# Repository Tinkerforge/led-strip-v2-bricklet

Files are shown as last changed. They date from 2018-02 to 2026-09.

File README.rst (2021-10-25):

LED Strip Bricklet 2.0
======================

This repository contains the firmware source code and the hardware design
files. The documentation generator configs can be found at
https://github.com/Tinkerforge/generators

Repository Content
------------------

software/:
 * examples/: Examples for all supported languages
 * build/: Compiled files
 * src/: Source code of firmware
 * Makefile: Makefile to build project

hardware/:
 * Contains KiCad project files and additionally schematics as PDF

datasheets/:
 * Contains datasheets for sensors and complex ICs that are used

Hardware
--------

The hardware is designed with the open source EDA Suite KiCad
(http://www.kicad.org). Before you are able to open the files,
you have to install the Tinkerforge kicad-libraries
(https://github.com/Tinkerforge/kicad-libraries). You can either clone
them directly in hardware/ or clone them in a separate folder and
symlink them into hardware/
(ln -s kicad_path/kicad-libraries project_path/hardware). After that you
can open the .pro file in hardware/ with KiCad and from there view and
modify the schematics and the PCB layout.

Software
--------

If you want to do your own Brick/Bricklet firmware development we highly
recommend that you use our build environment setup script and read the
tutorial (https://www.tinkerforge.com/en/doc/Tutorials/Tutorial_Build_Environment/Tutorial.html).

To compile the C code we recommend you to install the newest GNU Arm Embedded
Toolchain (https://launchpad.net/gcc-arm-embedded/+download).
You also need to install bricklib2 (https://github.com/Tinkerforge/bricklib2).

You can either clone it directly in software/src/ or clone it in a
separate folder and symlink it into software/src/
(ln -s bricklib_path/bricklib2 project_path/software/src/). Finally make sure to
have CMake installed (http://www.cmake.org/cmake/resources/software.html).

After that you can build the firmware by invoking make in software/.
The firmware (.zbin) can then be found in software/build/ and uploaded
with brickv (click button "Flashing" on start screen).

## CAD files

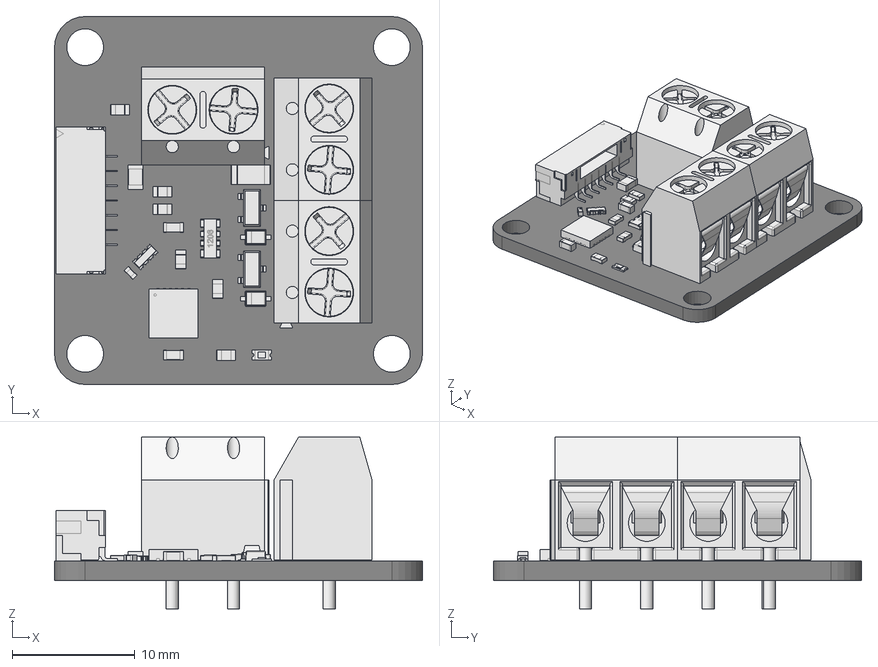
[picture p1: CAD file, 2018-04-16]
hardware/led-strip-v2.FCStd
30.0 x 30.0 x 14.0 mm
Pcb
SOD323F_
SOD323F_001
SOT23_
SOT23_001
2er_Buchse_
2er_Buchse_001
2er_Buchse_002
F_1206_
C_0402_
C_0805_
C_0603_
C_0603_001
R_0603_
BrickletConn_7pin_
R_0603_001
R_0603_002
R_4x0603_
QFN-24_4x4mm_Pitch0.5mm_
D_0603_blue_
R_0603_003
R_0603_004
R_0603_005

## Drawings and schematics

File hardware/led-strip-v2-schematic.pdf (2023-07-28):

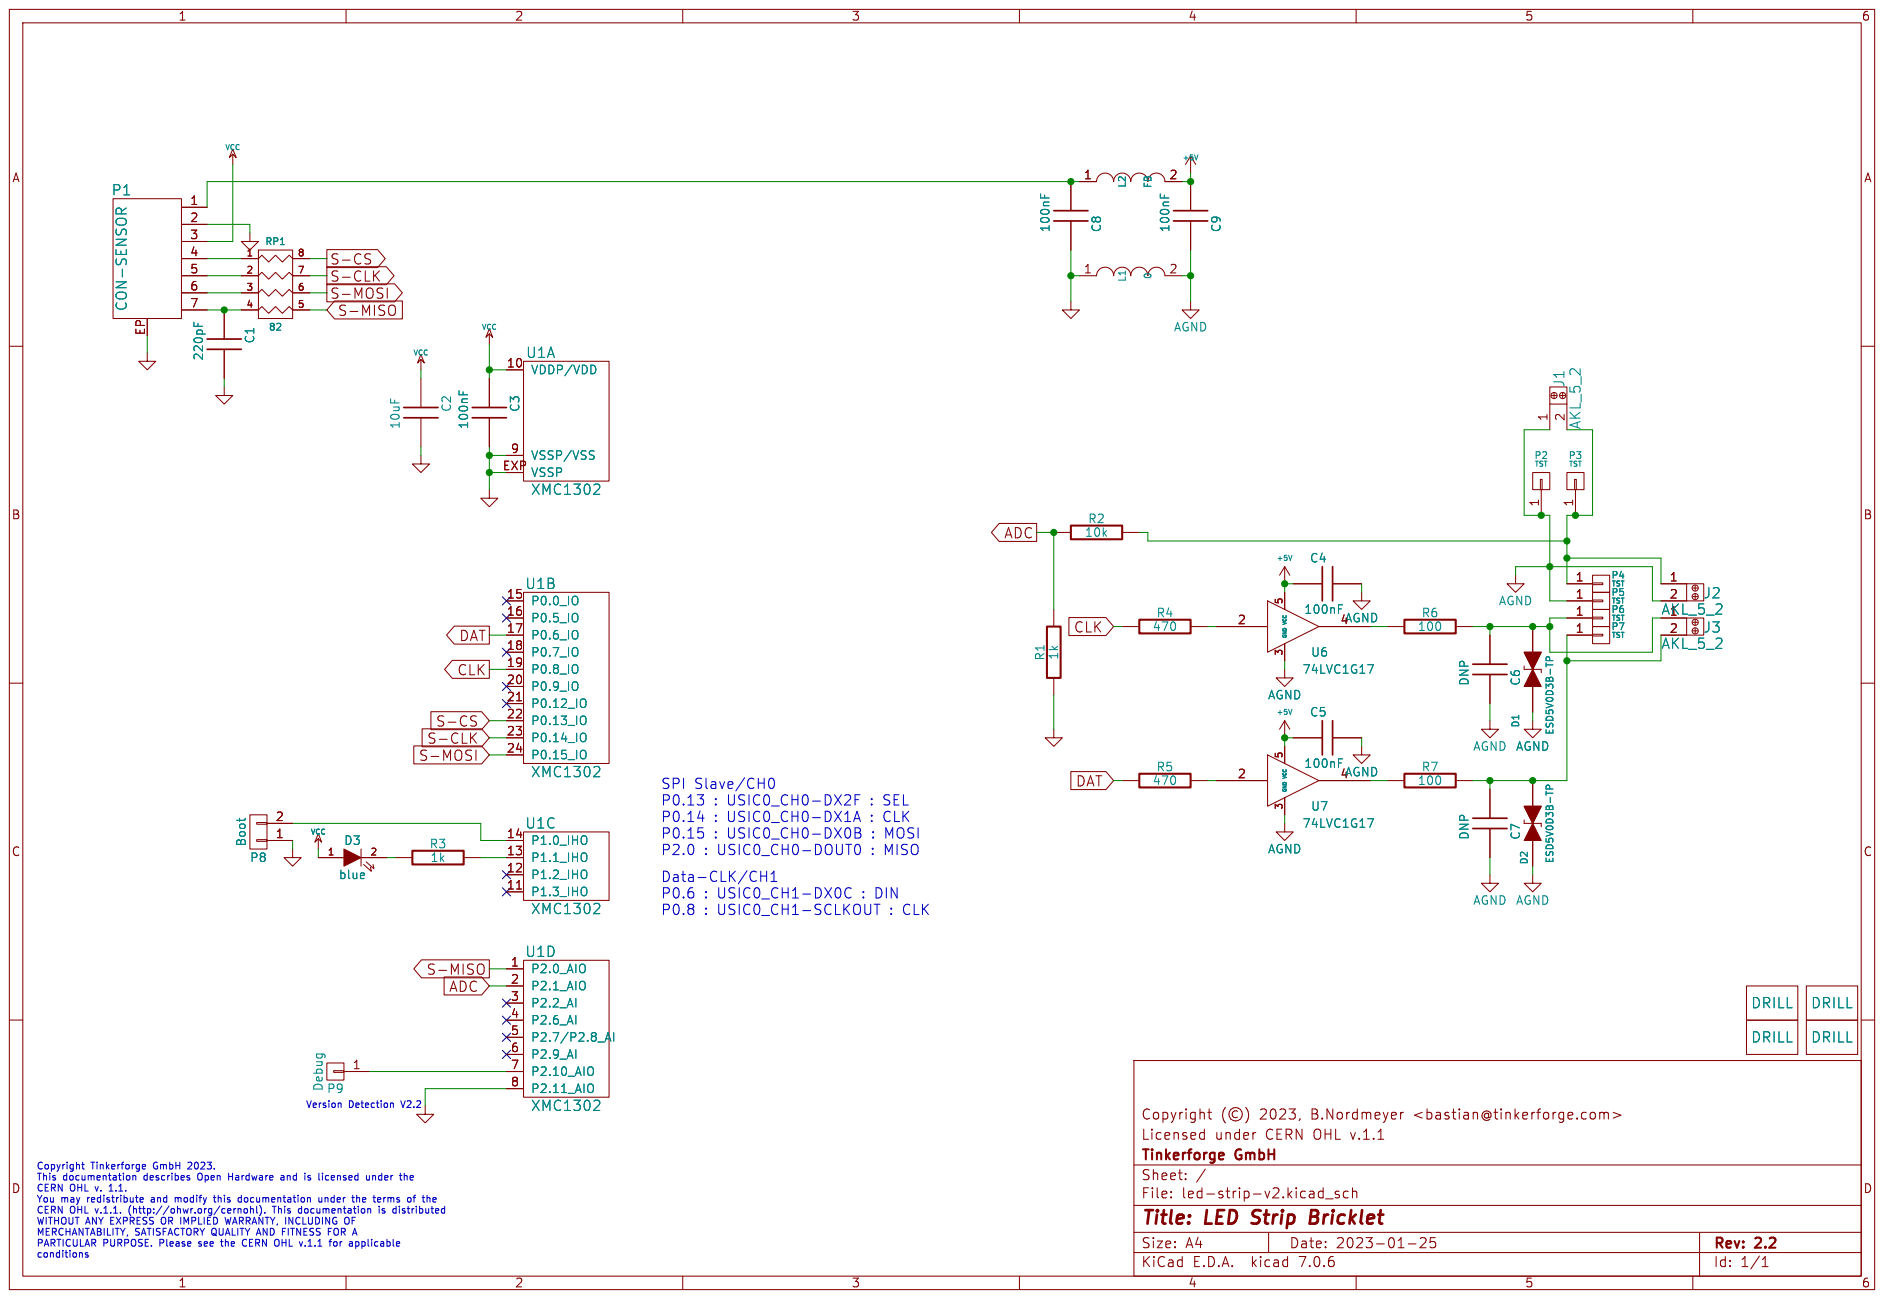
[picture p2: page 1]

Licensed | | under CERN OHL v.1.1 Copyright þÿ(©)2023, | B.Nordmeyer | <bastian@tinkerforge.com>

Id: 1/1 Title: LED Strip Bricklet File: led-strip-v2.kicad_sch Sheet: / Tinkerforge GmbH

PARTICULAR PURPOSE. Please see the CERN OHL v.1.1 for applicable

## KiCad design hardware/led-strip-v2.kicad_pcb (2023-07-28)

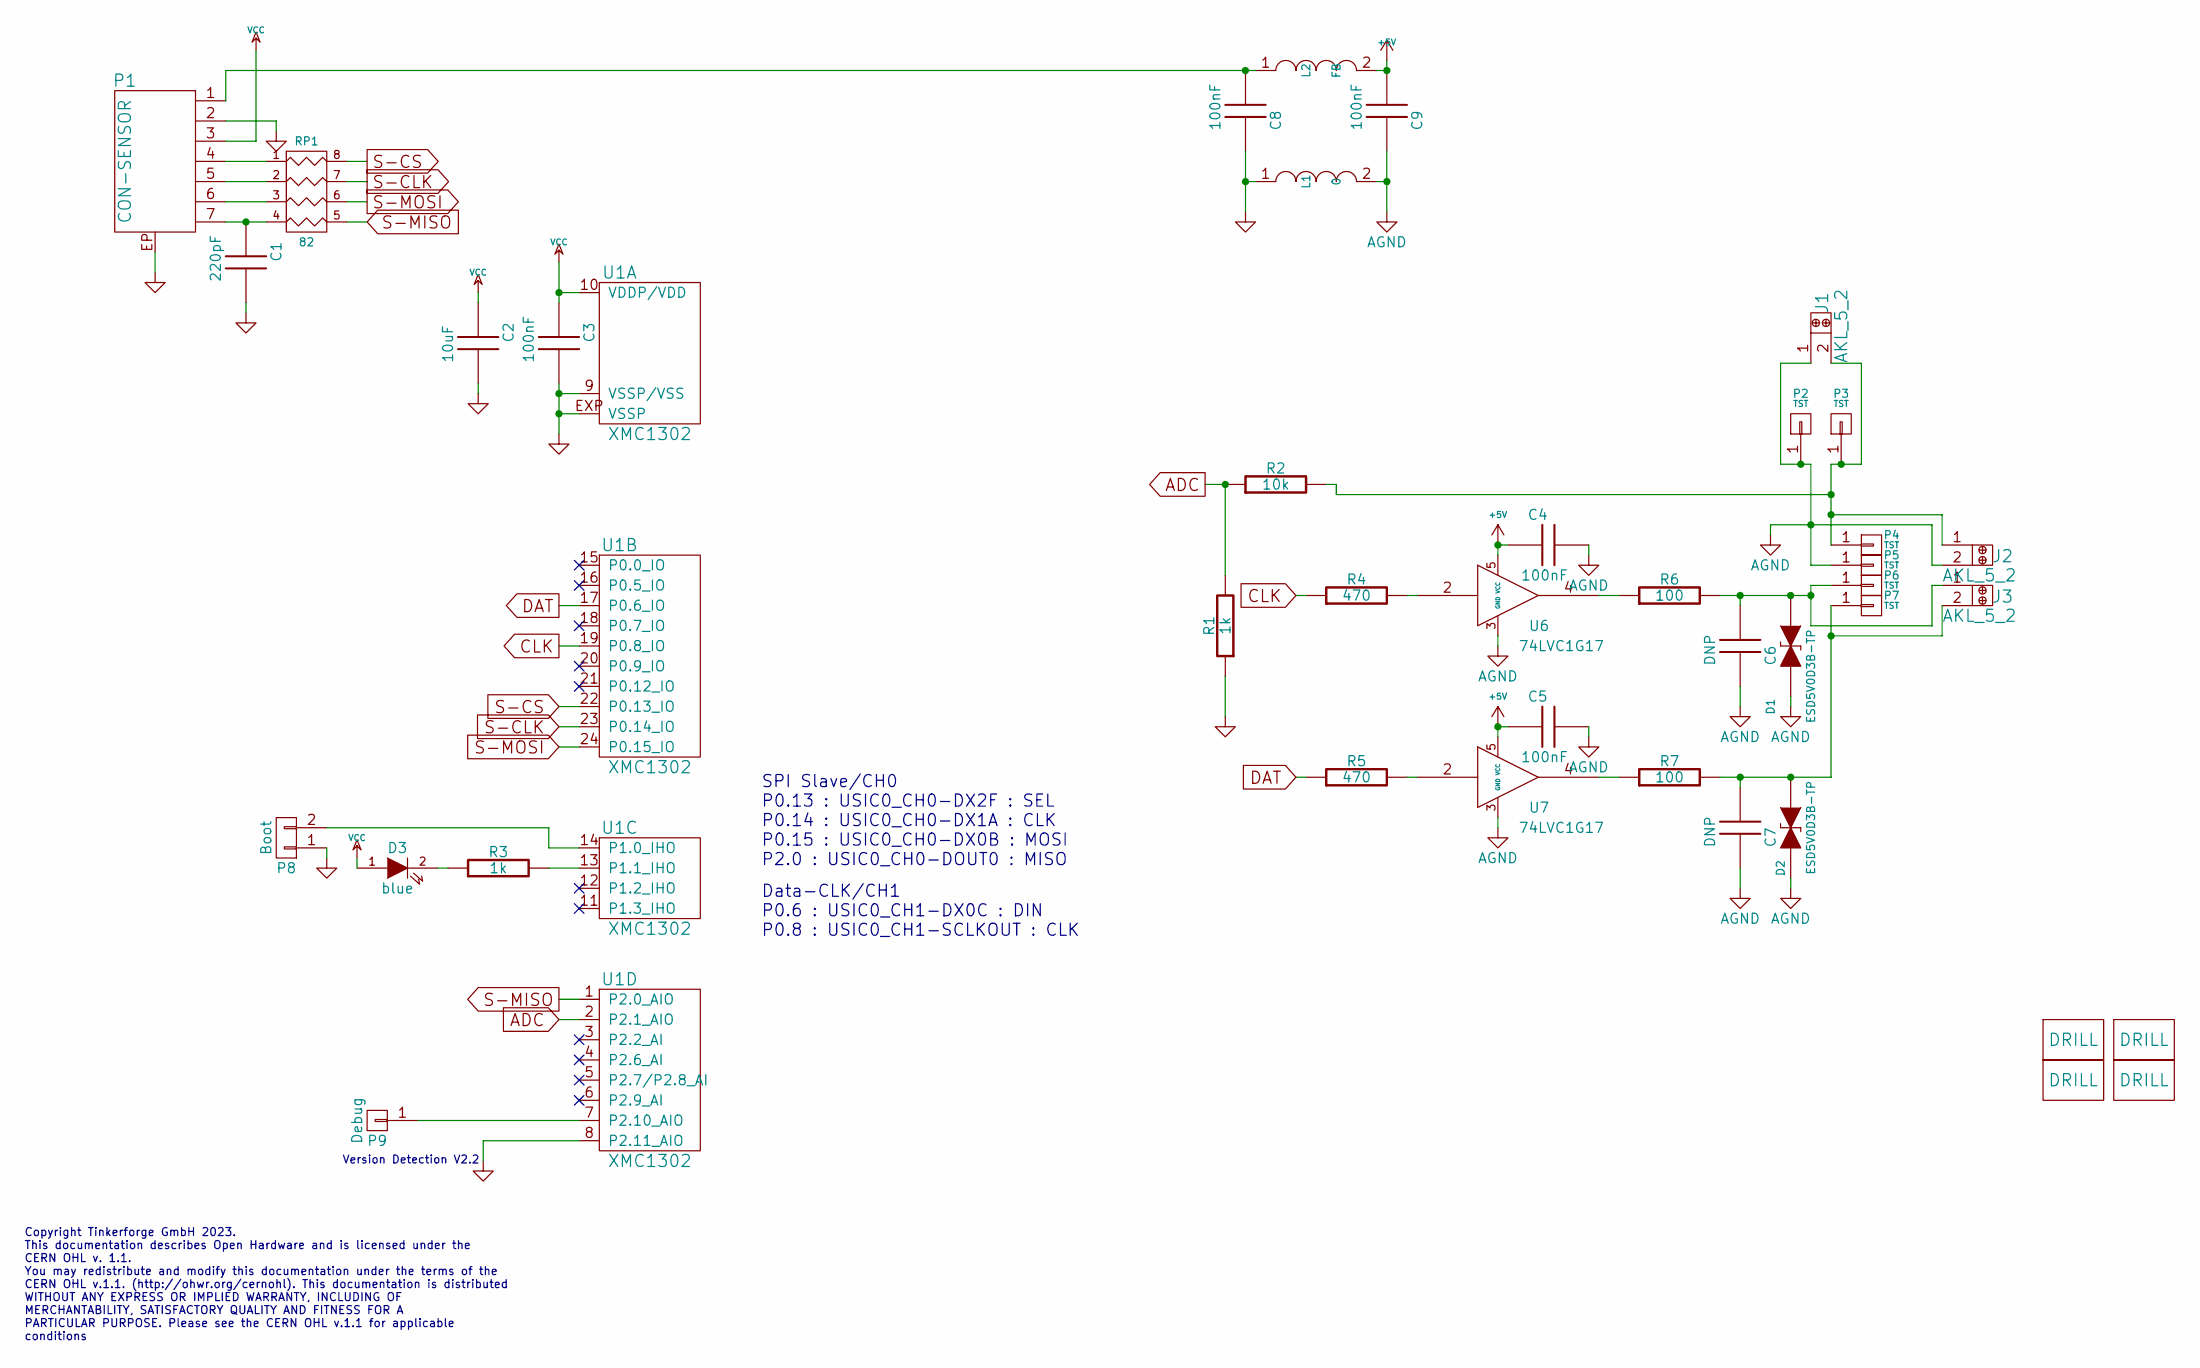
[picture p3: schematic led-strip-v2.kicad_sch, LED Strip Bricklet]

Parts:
C1: 220pF; C0402F
C2: 10uF; C0805E
C3, C4, C5, C8, C9: 100nF; C0603F
C6, C7: DNP; C0603F
D1, D2: ESD5V0D3B-TP; SOD-323
D3: blue; D0603F
J1, J2, J3: AKL_5_2
L1: 0; R0603F
L2: FB; R0603F
P1: CON-SENSOR; CON-SENSOR2
P2, P3, P4, P5, P6, P7: TST; SOLDER_PAD2
P8: Boot; SolderJumper
P9: Debug; DEBUG_PAD
R1, R3: 1k; R0603F
R2: 10k; R0603F
R4, R5: 470; R0603F
R6, R7: 100; R0603F
RP1: 82; 4X0402
U1: XMC1302; QFN24-4x4mm-0.5mm
U2, U3, U4, U5: DRILL; DRILL_NP
U6, U7: 74LVC1G17; SOT23-5

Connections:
+5V: C4.1, C5.1, C9.1, L2.2, U6.5 (VCC), U7.5 (VCC)
ADC: R1.2, R2.1, U1.2 (P2.1_AIO)
AGND: C4.2, C5.2, C6.2, C7.2, C9.2, D1.2 (K), D2.2 (K), J1.1, J2.2, L1.2, P2.1, P5.1, U6.3 (GND), U7.3 (GND)
CLK: R4.1, U1.19 (P0.8_IO)
DAT: R5.1, U1.17 (P0.6_IO)
GND: C1.2, C2.2, C3.2, C8.2, L1.1, P1.2, P1.EP, P8.1, R1.1, U1.8 (P2.11_AIO), U1.9 (VSSP/VSS), U1.EXP (VSSP)
unnamed: C1.1, P1.7, RP1.4
unnamed: C6.1, D1.1 (A), J3.1, P6.1, R6.2
unnamed: C7.1, D2.1 (A), J3.2, P7.1, R7.2
unnamed: C8.1, L2.1, P1.1
unnamed: D3.2 (K), R3.1
unnamed: J1.2, J2.1, P3.1, P4.1, R2.2
unnamed: P1.4, RP1.1
unnamed: P1.5, RP1.2
unnamed: P1.6, RP1.3
unnamed: P8.2, U1.14 (P1.0_IHO)
unnamed: P9.1, U1.7 (P2.10_AIO)
unnamed: R3.2, U1.13 (P1.1_IHO)
unnamed: R4.2, U6.2
unnamed: R5.2, U7.2
unnamed: R6.1, U6.4
unnamed: R7.1, U7.4
S-CLK: RP1.7 (R2), U1.23 (P0.14_IO)
S-CS: RP1.8 (R1), U1.22 (P0.13_IO)
S-MISO: RP1.5 (R4), U1.1 (P2.0_AIO)
S-MOSI: RP1.6 (R3), U1.24 (P0.15_IO)
VCC: C2.1, C3.1, D3.1 (A), P1.3, U1.10 (VDDP/VDD)

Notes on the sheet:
Copyright Tinkerforge GmbH 2023. This documentation describes Open Hardware and is licensed under the CERN OHL v. 1.1. You may redistribute and modify this documentation under the terms of the CERN OHL v.1.1. (http://ohwr.org/cernohl). This documentation is distributed WITHOUT ANY EXPRESS OR IMPLIE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
Version Detection V2.2
SPI Slave/CH0 P0.13 : USIC0_CH0-DX2F : SEL P0.14 : USIC0_CH0-DX1A : CLK P0.15 : USIC0_CH0-DX0B : MOSI P2.0 : USIC0_CH0-DOUT0 : MISO
Data-CLK/CH1 P0.6 : USIC0_CH1-DX0C : DIN P0.8 : USIC0_CH1-SCLKOUT : CLK

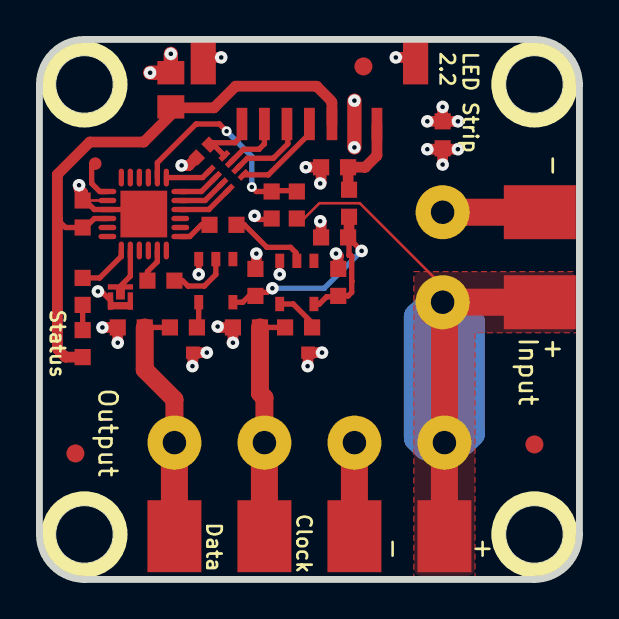
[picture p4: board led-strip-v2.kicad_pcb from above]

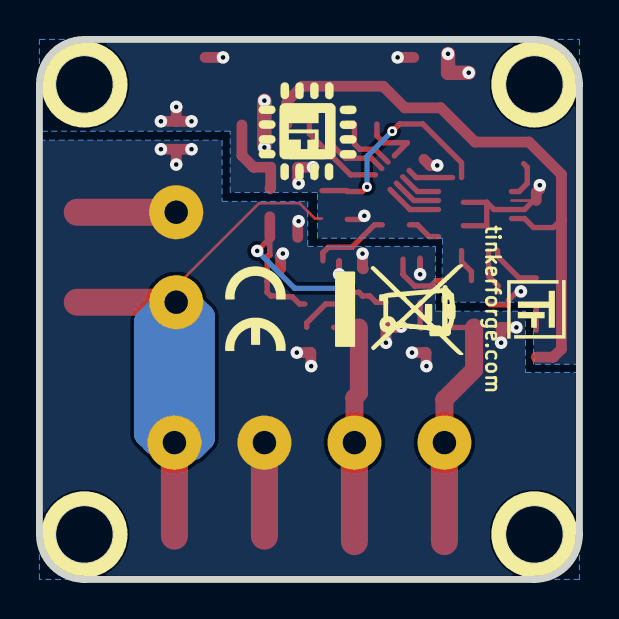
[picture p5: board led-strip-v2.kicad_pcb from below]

Board: 2 copper layers, 30.0 x 30.0 mm, 46 parts (2 on the bottom side), 27 nets.

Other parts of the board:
Fiducial_Mark: VAL**; Fiducial_Mark
Fiducial_Mark#2, Fiducial_Mark#3: VAL**; Fiducial_Mark
VAL: CE_5mm
VAL#2: WEEE_7mm

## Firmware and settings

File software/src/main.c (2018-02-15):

/* led-strip-v2-bricklet
 * Copyright (C) 2018 Olaf Lüke <olaf@tinkerforge.com>
 *
 * main.c: Initialization for LED Strip V2 Bricklet
 *
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
 * You should have received a copy of the GNU Lesser General Public
 * License along with this library; if not, write to the
 * Free Software Foundation, Inc., 59 Temple Place - Suite 330,
 * Boston, MA 02111-1307, USA.
 */

#include <stdio.h>
#include <stdbool.h>

#include "configs/config.h"

#include "bricklib2/bootloader/bootloader.h"
#include "bricklib2/hal/system_timer/system_timer.h"
#include "bricklib2/logging/logging.h"
#include "communication.h"
#include "led.h"

int main(void) {
	logging_init();
	logd("Start LED Strip V2 Bricklet\n\r");

	communication_init();
	led_init();

	while(true) {
		bootloader_tick();
		communication_tick();
		led_tick();
	}
}

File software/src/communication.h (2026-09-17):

/* led-strip-v2-bricklet
 * Copyright (C) 2018 Olaf Lüke <olaf@tinkerforge.com>
 *
 * communication.h: TFP protocol message handling
 *
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
 * You should have received a copy of the GNU Lesser General Public
 * License along with this library; if not, write to the
 * Free Software Foundation, Inc., 59 Temple Place - Suite 330,
 * Boston, MA 02111-1307, USA.
 */

#ifndef COMMUNICATION_H
#define COMMUNICATION_H

#include <stdint.h>
#include <stdbool.h>

#include "bricklib2/protocols/tfp/tfp.h"
#include "bricklib2/bootloader/bootloader.h"

// Default functions
BootloaderHandleMessageResponse handle_message(const void *data, void *response);
void communication_tick(void);
void communication_init(void);

// Constants

#define LED_STRIP_V2_CHIP_TYPE_WS2801 2801
#define LED_STRIP_V2_CHIP_TYPE_WS2811 2811
#define LED_STRIP_V2_CHIP_TYPE_WS2812 2812
#define LED_STRIP_V2_CHIP_TYPE_LPD8806 8806
#define LED_STRIP_V2_CHIP_TYPE_APA102 102

#define LED_STRIP_V2_CHANNEL_MAPPING_RGB 6
#define LED_STRIP_V2_CHANNEL_MAPPING_RBG 9
#define LED_STRIP_V2_CHANNEL_MAPPING_BRG 33
#define LED_STRIP_V2_CHANNEL_MAPPING_BGR 36
#define LED_STRIP_V2_CHANNEL_MAPPING_GRB 18
#define LED_STRIP_V2_CHANNEL_MAPPING_GBR 24
#define LED_STRIP_V2_CHANNEL_MAPPING_RGBW 27
#define LED_STRIP_V2_CHANNEL_MAPPING_RGWB 30
#define LED_STRIP_V2_CHANNEL_MAPPING_RBGW 39
#define LED_STRIP_V2_CHANNEL_MAPPING_RBWG 45
#define LED_STRIP_V2_CHANNEL_MAPPING_RWGB 54
#define LED_STRIP_V2_CHANNEL_MAPPING_RWBG 57
#define LED_STRIP_V2_CHANNEL_MAPPING_GRWB 78
#define LED_STRIP_V2_CHANNEL_MAPPING_GRBW 75
#define LED_STRIP_V2_CHANNEL_MAPPING_GBWR 108
#define LED_STRIP_V2_CHANNEL_MAPPING_GBRW 99
#define LED_STRIP_V2_CHANNEL_MAPPING_GWBR 120
#define LED_STRIP_V2_CHANNEL_MAPPING_GWRB 114
#define LED_STRIP_V2_CHANNEL_MAPPING_BRGW 135
#define LED_STRIP_V2_CHANNEL_MAPPING_BRWG 141
#define LED_STRIP_V2_CHANNEL_MAPPING_BGRW 147
#define LED_STRIP_V2_CHANNEL_MAPPING_BGWR 156
#define LED_STRIP_V2_CHANNEL_MAPPING_BWRG 177
#define LED_STRIP_V2_CHANNEL_MAPPING_BWGR 180
#define LED_STRIP_V2_CHANNEL_MAPPING_WRBG 201
#define LED_STRIP_V2_CHANNEL_MAPPING_WRGB 198
#define LED_STRIP_V2_CHANNEL_MAPPING_WGBR 216
#define LED_STRIP_V2_CHANNEL_MAPPING_WGRB 210
#define LED_STRIP_V2_CHANNEL_MAPPING_WBGR 228
#define LED_STRIP_V2_CHANNEL_MAPPING_WBRG 225

#define LED_STRIP_V2_BOOTLOADER_MODE_BOOTLOADER 0
#define LED_STRIP_V2_BOOTLOADER_MODE_FIRMWARE 1
#define LED_STRIP_V2_BOOTLOADER_MODE_BOOTLOADER_WAIT_FOR_REBOOT 2
#define LED_STRIP_V2_BOOTLOADER_MODE_FIRMWARE_WAIT_FOR_REBOOT 3
#define LED_STRIP_V2_BOOTLOADER_MODE_FIRMWARE_WAIT_FOR_ERASE_AND_REBOOT 4

#define LED_STRIP_V2_BOOTLOADER_STATUS_OK 0
#define LED_STRIP_V2_BOOTLOADER_STATUS_INVALID_MODE 1
#define LED_STRIP_V2_BOOTLOADER_STATUS_NO_CHANGE 2
#define LED_STRIP_V2_BOOTLOADER_STATUS_ENTRY_FUNCTION_NOT_PRESENT 3
#define LED_STRIP_V2_BOOTLOADER_STATUS_DEVICE_IDENTIFIER_INCORRECT 4
#define LED_STRIP_V2_BOOTLOADER_STATUS_CRC_MISMATCH 5

#define LED_STRIP_V2_STATUS_LED_CONFIG_OFF 0
#define LED_STRIP_V2_STATUS_LED_CONFIG_ON 1
#define LED_STRIP_V2_STATUS_LED_CONFIG_SHOW_HEARTBEAT 2
#define LED_STRIP_V2_STATUS_LED_CONFIG_SHOW_STATUS 3

// Function and callback IDs and structs
#define FID_SET_LED_VALUES_LOW_LEVEL 1
#define FID_GET_LED_VALUES_LOW_LEVEL 2
#define FID_SET_FRAME_DURATION 3
#define FID_GET_FRAME_DURATION 4
#define FID_GET_SUPPLY_VOLTAGE 5
#define FID_SET_CLOCK_FREQUENCY 7
#define FID_GET_CLOCK_FREQUENCY 8
#define FID_SET_CHIP_TYPE 9
#define FID_GET_CHIP_TYPE 10
#define FID_SET_CHANNEL_MAPPING 11
#define FID_GET_CHANNEL_MAPPING 12
#define FID_SET_FRAME_STARTED_CALLBACK_CONFIGURATION 13
#define FID_GET_FRAME_STARTED_CALLBACK_CONFIGURATION 14
#define FID_START_FRAME 15
#define FID_TRUNCATE_FRAME 16
#define FID_SET_AUTO_TRUNCATE 17
#define FID_GET_AUTO_TRUNCATE 18

#define FID_CALLBACK_FRAME_STARTED 6

typedef struct {
	TFPMessageHeader header;
	uint16_t index;
	uint16_t value_length;
	uint16_t value_chunk_offset;
	uint8_t value_chunk_data[58];
} __attribute__((__packed__)) SetLEDValuesLowLevel;

typedef struct {
	TFPMessageHeader header;
	uint16_t index;
	uint16_t length;
} __attribute__((__packed__)) GetLEDValuesLowLevel;

typedef struct {
	TFPMessageHeader header;
	uint16_t value_length;
	uint16_t value_chunk_offset;
	uint8_t value_chunk_data[60];
} __attribute__((__packed__)) GetLEDValuesLowLevel_Response;

typedef struct {
	TFPMessageHeader header;
	uint16_t duration;
} __attribute__((__packed__)) SetFrameDuration;

typedef struct {
	TFPMessageHeader header;
} __attribute__((__packed__)) GetFrameDuration;

typedef struct {
	TFPMessageHeader header;
	uint16_t duration;
} __attribute__((__packed__)) GetFrameDuration_Response;

typedef struct {
	TFPMessageHeader header;
} __attribute__((__packed__)) GetSupplyVoltage;

typedef struct {
	TFPMessageHeader header;
	uint16_t voltage;
} __attribute__((__packed__)) GetSupplyVoltage_Response;

typedef struct {
	TFPMessageHeader header;
	uint16_t length;
} __attribute__((__packed__)) FrameStarted_Callback;

typedef struct {
	TFPMessageHeader header;
	uint32_t frequency;
} __attribute__((__packed__)) SetClockFrequency;

typedef struct {
	TFPMessageHeader header;
} __attribute__((__packed__)) GetClockFrequency;

typedef struct {
	TFPMessageHeader header;
	uint32_t frequency;
} __attribute__((__packed__)) GetClockFrequency_Response;

typedef struct {
	TFPMessageHeader header;
	uint16_t chip;
} __attribute__((__packed__)) SetChipType;

typedef struct {
	TFPMessageHeader header;
} __attribute__((__packed__)) GetChipType;

typedef struct {
	TFPMessageHeader header;
	uint16_t chip;
} __attribute__((__packed__)) GetChipType_Response;

typedef struct {
	TFPMessageHeader header;
	uint8_t mapping;
} __attribute__((__packed__)) SetChannelMapping;

typedef struct {
	TFPMessageHeader header;
} __attribute__((__packed__)) GetChannelMapping;

typedef struct {
	TFPMessageHeader header;
	uint8_t mapping;
} __attribute__((__packed__)) GetChannelMapping_Response;

typedef struct {
	TFPMessageHeader header;
	bool enable;
} __attribute__((__packed__)) SetFrameStartedCallbackConfiguration;

typedef struct {
	TFPMessageHeader header;
} __attribute__((__packed__)) GetFrameStartedCallbackConfiguration;

typedef struct {
	TFPMessageHeader header;
	bool enable;
} __attribute__((__packed__)) GetFrameStartedCallbackConfiguration_Response;

typedef struct {
	TFPMessageHeader header;
} __attribute__((__packed__)) StartFrame;

typedef struct {
	TFPMessageHeader header;
	uint16_t length;
} __attribute__((__packed__)) TruncateFrame;

typedef struct {
	TFPMessageHeader header;
	uint16_t length;
} __attribute__((__packed__)) SetAutoTruncate;

typedef struct {
	TFPMessageHeader header;
} __attribute__((__packed__)) GetAutoTruncate;

typedef struct {
	TFPMessageHeader header;
	uint16_t length;
} __attribute__((__packed__)) GetAutoTruncate_Response;
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

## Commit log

2018-01-12 add new hardware prototype
    [led_strip.kicad_pcb, led_strip.sch]
2018-01-15 change default via size
    [led_strip.kicad_pcb]
2018-02-15 specify processor
    [led_strip.kicad_pcb, led_strip.sch]
2018-02-15 Add firmware
    [cmake_config_custom.txt]
2018-02-20 Cleanup KiCad libraries config
    Ensure LibDir=kicad-libraries and LibName1=tinkerforge.
    Remove special library.
2018-03-15 fix description text
    [led_strip.kicad_pcb]
2018-03-26 Make sure that LED type is updated during initialization
2018-04-16 Add 3d model (*.FCStd & *.step)
    [led_strip.FCStd]
2018-05-04 Rename files
    [led-strip-v2.FCStd, led-strip-v2.kicad_pcb, led-strip-v2.sch]
2018-05-04 Add schematic PDF
2018-05-30 remove solder paste layer of solder pads
    [led-strip-v2.kicad_pcb]
2018-06-11 Fix bit mixup in lookup table for WS281x LEDs
    [led.c]
2018-06-13 Fix schematic filename
2018-06-18 Change capacitor footprint(s) to C0402F
    [led-strip-v2.kicad_pcb, led-strip-v2.sch]
2018-11-12 Fill in incomplete LED Strip V2 Python examples
2019-05-29 Dont disable post calibration
2019-11-20 Rewrite get_led_values. Fix streaming.
    [led.c]
2020-06-10 version 2.1, improve ground connection
    [led-strip-v2.kicad_pcb, led-strip-v2.sch]
2020-08-04 specify fuse
    [led-strip-v2.kicad_pcb, led-strip-v2.sch]
2020-09-02 uc: Add example driver note.
2021-10-25 Update KiCad link
    https://www.kicad.org/blog/2021/10/Avoid-links-to-former-kicad-domain/
2022-08-23 add 2.2 data
    [led-strip-v2.kicad_pcb, led-strip-v2.sch]
2022-09-21 add version detection pin to pcb
    [led-strip-v2.kicad_pcb]
2023-01-23 New standart layout. Switched to Kicad 6
    [led-strip-v2.kicad_pcb, led-strip-v2.kicad_sch, led-strip-v2.sch]
2023-01-25 Data Cleanup
    [led-strip-v2.kicad_pcb, led-strip-v2.kicad_sch]
2023-07-28 update to kicad 7. updated schematic version v2.2 detection. updatet schematic pdf
    [led-strip-v2.kicad_pcb, led-strip-v2.kicad_sch]
2026-08-13 Add manual frame updates
2026-09-17 Add frame truncation

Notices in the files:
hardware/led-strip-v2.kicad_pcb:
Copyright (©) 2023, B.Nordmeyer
